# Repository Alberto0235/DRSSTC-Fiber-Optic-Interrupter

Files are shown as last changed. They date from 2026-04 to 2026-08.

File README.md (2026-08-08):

# ⚡ DRSSTC Fiber-Optic Interrupter — V1.2

<p align="left">
  
  
  
  
  
</p>

-----

## 📋 Project Summary

This repository contains the hardware design for a custom interrupter control board built for a Dual Resonant Solid State Tesla Coil (DRSSTC).

While the high-power driver is the "brain" of the system, the interrupter plays a fundamental role: it generates the PWM signal that is sent to the driver, which in turn generates the gate drive pulses to modulate the Tesla Coil's output.

Operating near a resonant RF system means dealing with significant EMI. To address this, the board relies on fiber optic transmitters to electrically isolate the control logic from the high-voltage side, alongside a controlled-impedance layout for high-speed digital interfaces and a hardware-level safety interlocking system.

Key features include:

  * **Total galvanic isolation** of the control outputs via 2 fiber optic channels, featuring a versatile dual-footprint design.
  * **Deterministic hardware safety chain** (E-brake) capable of cutting optical output power and halting MCU timers.
  * **Controlled-impedance routing** on USB, FSMC, and SDIO interfaces.
  * **Flexible power architecture** supporting USB-C bus power or an optional rechargeable battery (e.g., Samsung 30Q 3000mAh) via a dedicated charging IC and a 3.3V buck regulator.

-----

PCB Render

🔗 **Explore the design:** [View the full Schematic (PDF)](Hardware/Exports/Schematic_Interrupter_v1.2.pdf)
> **Status Note:** The hardware design, fabrication, and assembly are complete. The board is currently undergoing bench validation and bring-up, while firmware development (STM32CubeMX HAL + application layer) is in progress.

-----

## 🔧 Key Specifications & Features

| Parameter | Value / Detail |
|---|---|
| **MCU** | STM32F405VGT6 — ARM Cortex-M4 @ 168 MHz, LQFP-100 |
| **PCB Layers** | 4-layer controlled-impedance stackup (JLCPCB JLC04161H-3313) |
| **System Rail** | 3.3 V — generated by a synchronous buck converter |
| **Power Input** | USB-C (bus power) or Li-ion battery — Charger/Power-path: BQ24075RGT · Protection: BQ29700DSERG · Buck: TLV62569DBV |
| **Outputs** | 2x Galvanically isolated fiber optic channels (Dual-footprint: HFBR-1412TZ or IF E97) |
| **Optical Rail** | 3.3 V — Switched by a PMOS tied to the E-brake safety chain |
| **Safety Chain** | Hardware E-brake: cuts PMOS power + triggers interrupts to halt STM32 timers |
| **Display Interface** | FSMC 16-bit 8080 Mode — 50 Ω impedance-controlled. Target display: ER-TFT028A2-4 (IM3=0, IM2=0, IM1=0, IM0=1). |
| **Storage** | SD card via SDIO — 50 Ω impedance-controlled |
| **USB Interface** | Full-speed USB 2.0 — 90 Ω differential impedance |
| **Clock Source** | External 24 MHz crystal oscillator |
| **User Interface** | Rotary encoders + tactile push buttons |
| **External/Debug** | UART header (with 100 Ω series resistors) for debug or additional modules + Tag-Connect SWD |
| **Length Matching** | Applied on USB D+/D−, FSMC data/address bus, and SDIO data lines |
| **Design Tool** | KiCad 9.0 |

-----

## 🏆 Hardware Engineering Highlights

This section details some of the specific design choices made during the layout routing and stackup definition.

### 📡 Signal Integrity

  * **USB 2.0 (Full Speed):** The D+/D− pair is routed as a 90 Ω differential pair, calculated using the Saturn PCB Toolkit. Intra-pair skew is minimized across the routing path.
  * **FSMC & SDIO:** Routed at 50 Ω characteristic single-ended impedance. For the SDIO protocol, 33 Ω series termination resistors were placed as close as possible to the MCU source to suppress reflections.
  * **UART / External Header:** 100 Ω series resistors were added to the TX/RX lines near the connector. Since no TVS diodes were implemented at the silicon level for this header, these resistors provide a basic level of protection against spikes during manual probing or module connection.

| USB 2.0 (90 Ω Differential Target) | FSMC & SDIO (50 Ω Single-Ended Target) |
| :---: | :---: |
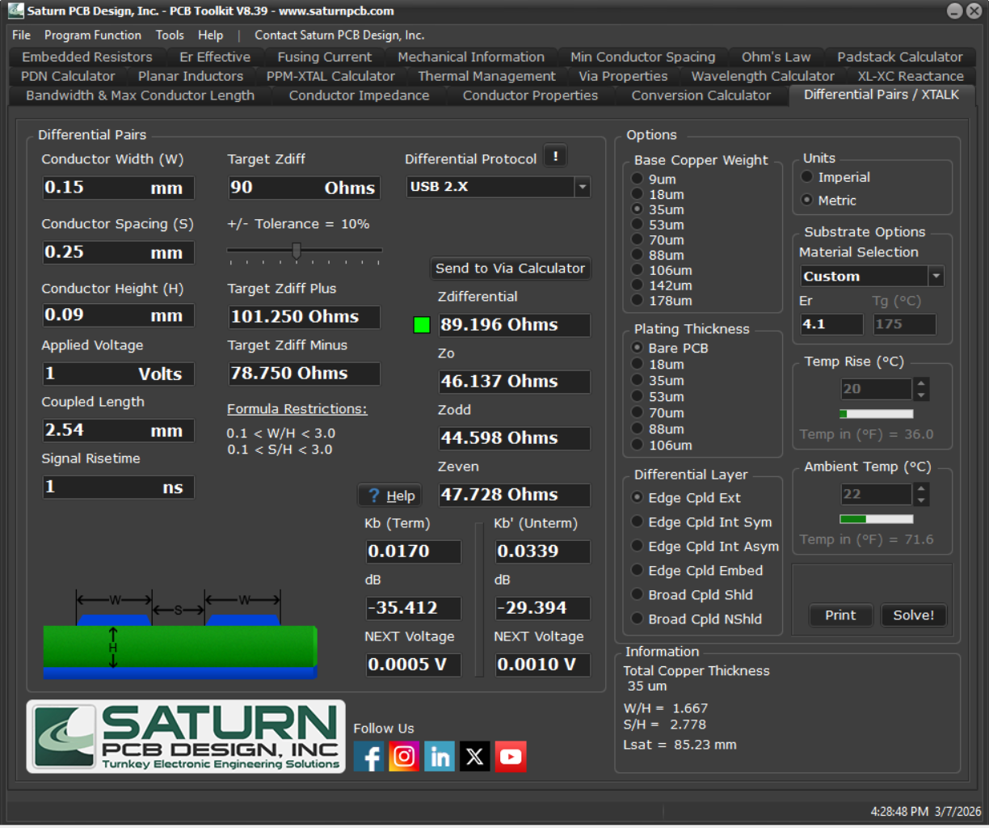
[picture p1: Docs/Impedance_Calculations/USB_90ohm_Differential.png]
Saturn PCB USB
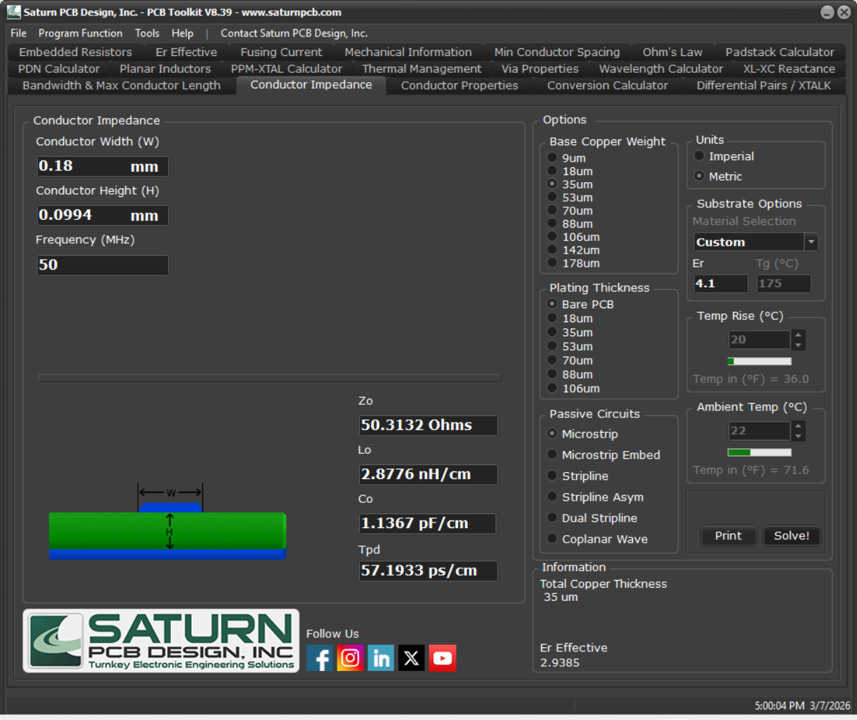
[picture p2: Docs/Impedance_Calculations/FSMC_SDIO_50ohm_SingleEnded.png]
Saturn PCB SDIO
|  |  |

### 🧱 Stackup & Routing Strategy

  * **4-Layer Stackup:** Configured as `Signal+PWR` / `GND` / `GND` / `Signal+PWR`.
  * **Return Paths:** Layers 2 and 3 provide solid, unbroken ground reference planes for the high-speed routing on the top and bottom layers.
  * **Layer Transitions:** Whenever a high-speed signal transitions from Layer 1 to Layer 4, adjacent GND stitching vias were placed next to the signal via to ensure an uninterrupted return current path between the two ground planes.

-----

## 🔒 Safety Architecture

  * **Galvanic Isolation & Transmitter Flexibility:** The commands sent to the driver leave the board exclusively through the fiber optic transmitters. This prevents ground loops and high-voltage transients from traveling back into the control board logic. To maximize flexibility, each of the two optical channels features a dual-footprint design. You can independently populate either an **HFBR-1412TZ** or an **IF E97** transmitter per channel. The onboard current-limiting resistors are specifically calculated and routed for these two standard components.
  * **Hardware E-brake Mechanism:**
      * The E-brake switch is normally closed (NC) to GND. When pressed — or if the cable is accidentally disconnected — a pull-up resistor drives the PMOS gate to 3.3 V, switching it off. This ensures the system fails safe on cable break, not just on deliberate actuation.
      * **Action 1 (Hardware):** Pressing the E-brake disconnects the GND path. This immediately switches off a PMOS on the 3.3V optical rail, physically de-energizing the fiber transmitters and guaranteeing zero output, completely independent of the microcontroller's state.
      * **Action 2 (MCU IRQ):** The same physical event asserts a hardware interrupt on the STM32, halting the PWM timers in the fastest possible IRQ context.
      * **Action 3 (Software IRQ):** A software-level handler serves as a secondary redundant stop mechanism.

-----

## 📁 Repository Structure

```text
DRSSTC-Interrupter/
│
├── Hardware/
│   ├── KiCad/
│   │   ├── Interrupter/              ← KiCad project files
│   │   └── Libraries/                ← Additional libraries
│   └── Exports/
│       ├── Schematic_Interrupter_v1.2.pdf
│       └── PCB_v1.2.png
│
├── Fabrication/
│   ├── Gerbers/
│   ├── BOM_Interrupter_v1.2.csv
│   └── InteractiveBOM.html
│
├── Docs/
│   ├── Impedance_Calculations/
│   │   ├── USB_90ohm_Differential.png
│   │   └── FSMC_SDIO_50ohm_SingleEnded.png
│   └── Stackup/
│       └── JLCPCB_Stackup_Reference.png
│
├── Firmware/
│   └── STM32CubeMX/
│       └── Interrupter.ioc           ← Peripheral configuration (WIP)
│
└── README.md
```

-----

## 🛠️ Tools Used

| Tool | Version | Purpose |
|---|---|---|
| **KiCad EDA** | 9.0 | Full schematic capture and 4-layer PCB layout |
| **STM32CubeMX** | 6.16.0 | MCU peripheral configuration, clock tree, HAL code generation *(WIP)* |
| **Saturn PCB Toolkit** | 8.39 | Controlled impedance calculation (90 Ω differential and 50 Ω single-ended) |

-----

## ⚠️ Disclaimer

This project outlines a control board intended for use with high-voltage equipment capable of generating potentially lethal electrical discharges. All hardware documentation in this repository is provided **for educational and portfolio purposes only**. The author assumes no liability for any damage, injury, or loss resulting from the use or misuse of this material.

-----

## 👤 Author

**Alberto Marrone**
MSc Student in Electronics Engineering — Politecnico di Milano [LinkedIn](https://linkedin.com/in/alberto-marrone-444192274)

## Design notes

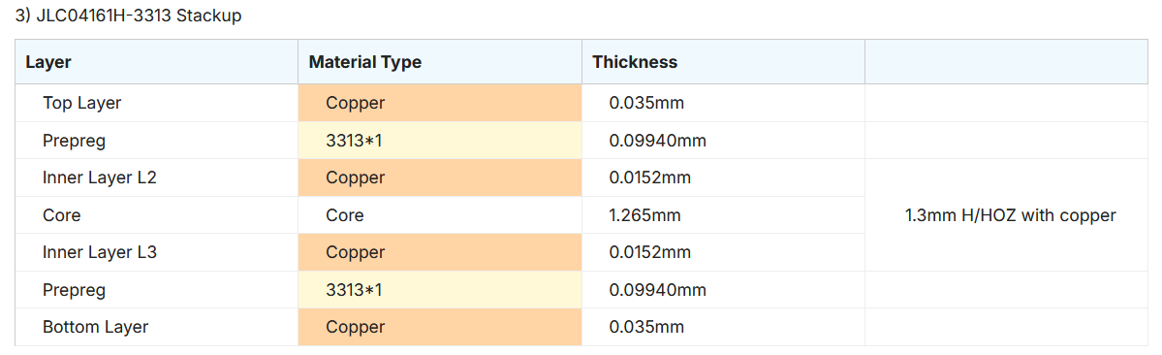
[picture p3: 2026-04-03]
Docs/Stackup/JLCPCB_Stackup_Reference.png

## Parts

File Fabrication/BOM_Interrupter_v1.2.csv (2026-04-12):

Reference | Qty | Value | DNP | Exclude from BOM | Exclude from Board | Footprint | Datasheet | Manufacturer_Part_Number | Vendor | Link
BT1 | 1 | Keystone 1043 |  |  |  | Imported:Keystone 1043 | https://www.mouser.it/datasheet/3/201/1/1043.pdf | 1043 | Mouser | https://www.mouser.it/ProductDetail/Keystone-Electronics/1043?qs=%2F7TOpeL5Mz6j%2FnxeOA1rsg%3D%3D
C1,C6,C7,C9,C11,C12,C13,C14,C15,C16,C17,C19,C22,C23,C25,C26,C30,C32,C37,C38,C39,C40,C41,C42,C47,C49,C50,C52,C53,C55,C56,C57,C58 | 33 | 100n |  |  |  | Capacitor_SMD:C_0402_1005Metric | https://pim.murata.com/asset/pim4/ceramicCapacitorSMD/GRT155R71H104KE01-01A-EN_PDF_CERAMICCAPACITORSMD | GRT155R71H104KE01J | Mouser | https://www.mouser.it/ProductDetail/Murata-Electronics/GRT155R71H104KE01J?qs=d0WKAl%252BL4Kar2U0zDlkjeg%3D%3D
C2,C8,C20,C21 | 4 | 2.2u |  |  |  | Capacitor_SMD:C_0805_2012Metric | https://datasheets.kyocera-avx.com/KGM_X7R.pdf | KGM21AR71E225KU | Mouser | https://www.mouser.it/ProductDetail/KYOCERA-AVX/KGM21AR71E225KU?qs=Jm2GQyTW%2FbhCn4KuUMBp1Q%3D%3D
C3,C4,C31 | 3 | 10p |  |  |  | Capacitor_SMD:C_0402_1005Metric | https://pim.murata.com/asset/pim4/ceramicCapacitorSMD/GRM1555C1H100FA01-01A-EN_PDF_CERAMICCAPACITORSMD | GRM1555C1H100FA01D | Mouser | https://www.mouser.it/ProductDetail/Murata-Electronics/GRM1555C1H100FA01D?qs=ouTquLLW2S6Ql85QMjDTPQ%3D%3D
C5,C18,C36,C48 | 4 | 1u |  |  |  | Capacitor_SMD:C_0603_1608Metric | https://product.tdk.com/system/files/dam/doc/product/capacitor/ceramic/mlcc/catalog/mlcc_commercial_general_en.pdf | C1608X7R1H105K080AB | Mouser | https://www.mouser.it/ProductDetail/TDK/C1608X7R1H105K080AB?qs=efUn273yAhdzCWVW9RXgig%3D%3D
C10,C24,C29,C35,C51,C54 | 6 | 4.7u |  |  |  | Capacitor_SMD:C_0805_2012Metric | https://www.mouser.it/datasheet/3/76/3/GRM21BZ7YA475KE15_01A.pdf | GRM21BZ7YA475KE15K | Mouser | https://www.mouser.it/ProductDetail/Murata-Electronics/GRM21BZ7YA475KE15K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
C27,C28,C33,C34 | 4 | 10u |  |  |  | Capacitor_SMD:C_0805_2012Metric | https://www.mouser.it/datasheet/3/76/2/GRM21BZ71E106KE15_01A.pdf | GRM21BZ71E106KE15L | Mouser | https://www.mouser.it/ProductDetail/Murata-Electronics/GRM21BZ71E106KE15L?qs=Ey7%2FXF42M3fdXe9bIpCO9w%3D%3D
C43,C44,C45,C46 | 4 | 10n |  |  |  | Capacitor_SMD:C_0603_1608Metric | https://datasheets.kyocera-avx.com/AutoMLCCKAF.pdf | KAF15AR71H103JM | Mouser | https://www.mouser.it/ProductDetail/KYOCERA-AVX/KAF15AR71H103JM?qs=OcgtsXO%252B3gvrQfm2NimJjQ%3D%3D
D1,D2,D3,D4,D5,D7,D9 | 7 | LED |  |  |  | Imported:TOPLED E1608 | https://eu.mouser.com/datasheet/3/5912/1/KB_DELSS2.12_EN.pdf,https://eu.mouser.com/datasheet/3/5912/1/KO_DELPS1.22_EN.pdf,https://eu.mouser.com/datasheet/3/59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 | KB DELSS2.12-THUH-34-2686,KO DELPS1.22-UGVI-24-H3Q4-20-S,KS DELPS1.22-TIVH-68-H3Q4-20-S,KT DELSS1.12-AYBZ-36-N626 | Mouser | https://eu.mouser.com/ProductDetail/ams-OSRAM/KB-DELSS2.12-THUH-34-2686
D6,D8 | 2 | IF-E97 |  |  |  | Imported:IF-E97 | https://i-fiberoptics.com/pdf/ife97-2-20.pdf | IF-E97 | DigiKey | https://www.digikey.es/es/products/detail/industrial-fiber-optics/IF-E97/272338
ENC1,ENC2 | 2 | PEC11R-4220F-S0024 |  |  |  | Imported:PEC11R4220FS0024 | https://www.bourns.com/docs/Product-Datasheets/PEC11R.pdf | PEC11R-4220F-S0024 | Mouser | https://www.mouser.it/ProductDetail/Bourns/PEC11R-4015F-S0024?qs=Zq5ylnUbLm4l0nvCUCX4Xw%3D%3D
FB1,FB2,FB3 | 3 | 120Ω @ 100MHz |  |  |  | Inductor_SMD:L_0603_1608Metric | https://eu.mouser.com/datasheet/3/76/2/QNFA9122.pdf | BLM18SG121TZ1D | Mouser | https://eu.mouser.com/ProductDetail/Murata-Electronics/BLM18SG121TZ1D?qs=lEfY3O89AqkcqxjERGLMfg%3D%3D
FID1,FID2,FID3,FID4,FID5,FID6 | 6 | Fiducial |  | Excluded from BOM |  | Fiducial:Fiducial_1mm_Mask2mm | ~ | Fiducial | ~ | ~
H1,H2,H3,H4 | 4 | M3 |  | Excluded from BOM |  | MountingHole:MountingHole_3.2mm_M3_Pad_Via | ~ | MountingHole-M3 | ~ | ~
IC1 | 1 | STM32F405VGT6 |  |  |  | Imported:STM32F405VGT6 | https://www.st.com/resource/en/datasheet/stm32f405zg.pdf | STM32F405VGT6 | Mouser | https://www.mouser.it/ProductDetail/STMicroelectronics/STM32F405VGT6?qs=Z8%252BeY1k3TIJiWie7HpfDCQ%3D%3D
IC2 | 1 | BQ29700DSER |  |  |  | Imported:BQ29700 | http://www.ti.com/lit/ds/symlink/bq2971.pdf | BQ29700DSER | Mouser | https://eu.mouser.com/ProductDetail/Texas-Instruments/BQ29700DSER?qs=%2Fd%252BFzHvH4c3zNh7Hkm%2Fvbw%3D%3D
J1 | 1 | Conn_01x04 |  |  |  | Connector_PinSocket_2.00mm:PinSocket_1x04_P2.00mm_Vertical | ~ | ~ | ~ | ~
J2 | 1 | USB_C_Receptacle_USB2.0_16P |  |  |  | Connector_USB:USB_C_Receptacle_GCT_USB4105-xx-A_16P_TopMnt_Horizontal | https://www.mouser.com/catalog/specsheets/Global_Connector_Technology_usb4105.pdf | USB4105-GF-A-120 | Mouser | https://eu.mouser.com/ProductDetail/GCT/USB4105-GF-A-120?qs=QNEnbhJQKva%252Bjxw%2FpEjDhQ%3D%3D
J3 | 1 | TagConnect |  | Excluded from BOM |  | Connector:Tag-Connect_TC2030-IDC-NL_2x03_P1.27mm_Vertical | https://www.tag-connect.com/wp-content/uploads/bsk-pdf-manager/TC2030-CTX_1.pdf | ~ | ~ | ~
J4 | 1 | ER-CON50HT-1 |  |  |  | Imported:ER-CON50HT-1 | https://www.buydisplay.com/download/connector/ER-CON50HT-1.pdf | ER-CON50HT-1 | BuyDispaly | https://www.buydisplay.com/50-pin-0-5mm-pitch-top-contact-zif-connector-fpc-connector
J5 | 1 | DM3AT-SF-PEJM5 |  |  |  | Imported:DM3AT-SF-PEJM5 | https://www.mouser.it/datasheet/3/731/1/DM3AT_SF_PEJM5_CL0609_0031_0_00_2DDrawing_0000947170.pdf | DM3AT-SF-PEJM5 | Mouser | https://www.mouser.it/ProductDetail/Hirose-Connector/DM3AT-SF-PEJM5?qs=LZSZKJVF%252B2WTDKp%252BR7IYAQ%3D%3D
JP1,JP2,JP3,JP4 | 4 | SolderJumper |  | Excluded from BOM |  | Jumper:SolderJumper-3_P1.3mm_Bridged2Bar12_RoundedPad1.0x1.5mm_NumberLabels | ~ | SolderJumper | ~ | ~
L1 | 1 | 2.2u |  |  |  | Imported:ETQ-P3M2R2HFP | https://industrial.panasonic.com/cdbs/www-data/pdf/AGL0000/AGL0000C67.pdf | ETQ-P3M2R2HFP | Mouser | https://www.mouser.it/ProductDetail/Panasonic/ETQ-P3M2R2HFP?qs=f9yNj16SXrJQaaX5knv6PA%3D%3D
Q1,Q2,Q4,Q5,Q6 | 5 | PMV240ENEAR |  |  |  | Package_TO_SOT_SMD:SOT-23 | https://assets.nexperia.com/documents/data-sheet/PMV240ENEA.pdf | PMV240ENEAR | Mouser | https://www.mouser.it/ProductDetail/Nexperia/PMV240ENEAR?qs=olJun0bQHM8vrl7UqGNaQw%3D%3D
Q3 | 1 | PMV250EPEAR |  |  |  | Package_TO_SOT_SMD:SOT-23 | https://assets.nexperia.com/documents/data-sheet/PMV250EPEA.pdf | PMV250EPEA | Mouser | https://www.mouser.it/ProductDetail/Nexperia/PMV250EPEAR?qs=Yna0arPQ0CTtAa8k6X9CyQ%3D%3D
R1,R2,R3,R5,R8,R9 | 6 | 33 |  |  |  | Resistor_SMD:R_0402_1005Metric | https://www.vishay.com/docs/20132/rca-sre3.pdf | RCA040233R0FKEDSR | Mouser | https://eu.mouser.com/ProductDetail/Vishay/RCA040233R0FKEDSR?qs=4dK74SdgGtwI6tlGJ%2FGTmQ%3D%3D
R4,R12,R16,R25,R26,R34,R42,R43,R44,R45,R46,R47,R48,R49,R50,R51,R52,R53,R54,R55,R56,R57,R58,R59,R60,R61,R67,R76 | 28 | 10k |  |  |  | Resistor_SMD:R_0402_1005Metric | https://eu.mouser.com/datasheet/3/508/1/PYU_AC_51_ROHS_L.pdf | AC0402FR-0710KL | Mouser | https://eu.mouser.com/ProductDetail/YAGEO/AC0402FR-0710KL?qs=yhV1fb9g%2FKYkR5U3B7upEQ%3D%3D
R6,R7,R11,R15,R79 | 5 | 100 |  |  |  | Resistor_SMD:R_0402_1005Metric | https://eu.mouser.com/datasheet/3/508/1/PYU_AC_51_ROHS_L.pdf | AC0402FR-13100RL | Mouser | https://eu.mouser.com/ProductDetail/YAGEO/AC0402FR-13100RL?qs=AQlKX63v8RslM5cufGduxw%3D%3D
R10 | 1 | 0 |  |  |  | Resistor_SMD:R_0402_1005Metric | https://www.vishay.com/docs/20035/dcrcwe3.pdf | CRCW04020000Z0ED | Mouser | https://eu.mouser.com/ProductDetail/Vishay/CRCW04020000Z0ED?qs=OlqPY1Ciranv3qgeAHCodg%3D%3D
R13,R40,R71,R77 | 4 | 220 |  |  |  | Resistor_SMD:R_0402_1005Metric | https://eu.mouser.com/datasheet/3/508/1/PYU_AC_51_ROHS_L.pdf | AC0402FR-7W220RL | Mouser | https://eu.mouser.com/ProductDetail/YAGEO/AC0402FR-7W220RL?qs=mQk0km4IMDd0ZPGIeAEF8Q%3D%3D
R14,R35,R41,R72,R78 | 5 | 100k |  |  |  | Resistor_SMD:R_0402_1005Metric | https://eu.mouser.com/datasheet/3/508/1/PYU_AC_51_ROHS_L.pdf | AC0402FR-7W100KL | Mouser | https://eu.mouser.com/ProductDetail/YAGEO/AC0402FR-7W100KL?qs=mQk0km4IMDfW7chanOKcig%3D%3D
R17,R18 | 2 | 5.1k |  |  |  | Resistor_SMD:R_0402_1005Metric | https://eu.mouser.com/datasheet/3/508/1/PYu-AF_51_RoHS_L_9.pdf | AF0402FR-075K1L | Mouser | https://eu.mouser.com/ProductDetail/YAGEO/AF0402FR-075K1L?qs=HEu%2FF%2FCqxzKC2GH3mOffUw%3D%3D
R19,R20,R29 | 3 | 1.5k |  |  |  | Resistor_SMD:R_0402_1005Metric | https://eu.mouser.com/datasheet/3/508/1/PYU_AC_51_ROHS_L.pdf | AC0402FR-7W1K5L | Mouser | https://eu.mouser.com/ProductDetail/YAGEO/AC0402FR-7W1K5L?qs=mQk0km4IMDcl1A2lKmX%2F2w%3D%3D
R21 | 1 | 330 |  |  |  | Resistor_SMD:R_0402_1005Metric | https://eu.mouser.com/datasheet/3/508/1/PYU_AC_51_ROHS_L.pdf | AC0402FR-7W330RL | Mouser | https://eu.mouser.com/ProductDetail/YAGEO/AC0402FR-7W330RL?qs=mQk0km4IMDczemHdChyFNA%3D%3D
R22 | 1 | 2.2k |  |  |  | Resistor_SMD:R_0402_1005Metric | https://eu.mouser.com/datasheet/3/508/1/PYu-AF_51_RoHS_L_9.pdf | AF0402FR-072K2L | Mouser | https://eu.mouser.com/ProductDetail/YAGEO/AF0402FR-072K2L?qs=HEu%2FF%2FCqxzLbE%252B9PoedSew%3D%3D
R23,R24 | 2 | 5.1M |  |  |  | Resistor_SMD:R_0402_1005Metric | https://eu.mouser.com/datasheet/3/508/1/PYu-AF_51_RoHS_L_9.pdf | AF0402FR-075M1L | Mouser | https://eu.mouser.com/ProductDetail/YAGEO/AF0402FR-075M1L?qs=tggtontpCXODq21yFdoYyQ%3D%3D
R27 | 1 | 68k |  |  |  | Resistor_SMD:R_0402_1005Metric | https://eu.mouser.com/datasheet/3/508/1/PYU_AC_51_ROHS_L.pdf | AC0402FR-7W68KL | Mouser | https://eu.mouser.com/ProductDetail/YAGEO/AC0402FR-7W68KL?qs=mQk0km4IMDe05rLmfXlp6Q%3D%3D
R28 | 1 | 1.8k |  |  |  | Resistor_SMD:R_0402_1005Metric | https://eu.mouser.com/datasheet/3/508/1/PYU_AC_51_ROHS_L.pdf | AC0402FR-071K8L | Mouser | https://eu.mouser.com/ProductDetail/YAGEO/AC0402FR-071K8L?qs=yhV1fb9g%2FKZuYNO5wsV9Pw%3D%3D
R30 | 1 | 470 |  |  |  | Resistor_SMD:R_0402_1005Metric | https://eu.mouser.com/datasheet/3/508/1/PYU_AC_51_ROHS_L.pdf | AC0402FR-7W470RL | Mouser | https://eu.mouser.com/ProductDetail/YAGEO/AC0402FR-7W470RL?qs=mQk0km4IMDfWG48tCLZa0w%3D%3D
R31,R32,R62,R63,R64,R65,R66 | 7 | 47k |  |  |  | Resistor_SMD:R_0402_1005Metric | https://www.vishay.com/docs/20035/dcrcwe3.pdf | CRCW040247K0FKED | Mouser | https://eu.mouser.com/ProductDetail/Vishay/CRCW040247K0FKED?qs=rzhQWu8UUS0SPbmGf0DOIg%3D%3D
R33 | 1 | 453k |  |  |  | Resistor_SMD:R_0402_1005Metric | https://industrial.panasonic.com/cdbs/www-data/pdf/RDA0000/AOA0000C304.pdf | ERJ-2RKF4533X | Mouser | https://eu.mouser.com/ProductDetail/Panasonic/ERJ-2RKF4533X?qs=YMBIwoNQYdVZQ316LHSXpQ%3D%3D
R36,R37,R38,R39 | 4 | 4.7 |  |  |  | Resistor_SMD:R_0402_1005Metric | https://eu.mouser.com/datasheet/3/508/1/PYu-SR_20105_RoHS_L_12.pdf | SR0402FR-7T4R7L | Mouser | https://eu.mouser.com/ProductDetail/YAGEO/SR0402FR-7T4R7L?qs=qpJ%252B%252B%252Bdg6p1e9tckOyHPxA%3D%3D
R68,R73 | 2 | 27 |  |  |  | Resistor_SMD:R_0805_2012Metric | https://industrial.panasonic.com/cdbs/www-data/pdf/RDO0000/AOA0000C331.pdf | ERJ-P06F27R0V | Mouser | https://eu.mouser.com/ProductDetail/Panasonic/ERJ-P06F27R0V?qs=iIVTEDlrHA3pDyX1uO2THw%3D%3D
R69,R70,R74,R75 | 4 | 47 |  |  |  | Resistor_SMD:R_0805_2012Metric | https://industrial.panasonic.com/cdbs/www-data/pdf/RDO0000/AOA0000C331.pdf | ERJ-P06F47R0V | Mouser | https://eu.mouser.com/ProductDetail/Panasonic/ERJ-P06F47R0V?qs=iIVTEDlrHA3jXurJ8%2Fb0wQ%3D%3D
SW1,SW2 | 2 | Push |  |  |  | Imported:PTS636SM43JSMTRLFS | https://www.ckswitches.com/media/2779/pts636.pdf | PTS636SM43JSMTR LFS | Mouser | https://eu.mouser.com/ProductDetail/CK/PTS636SM43JSMTR-LFS?qs=%252BXxaIXUDbq0c6yfQESkQsA%3D%3D
SW3 | 1 | SW_DIP_x02 |  |  |  | Imported:A6S-2104-H | https://eu.mouser.com/datasheet/3/39/1/en_a6s.pdf | A6S-2104-H | Mouser | https://eu.mouser.com/ProductDetail/Omron-Electronics/A6S-2104-H?qs=ZP3UR5XsUocCV6WIDeBAHA%3D%3D
SW4 | 1 | SW_SPDT |  |  |  | Imported:EG1206 | https://eu.mouser.com/datasheet/3/315/1/EG1206.pdf | EG1206 | Mouser | https://eu.mouser.com/ProductDetail/E-Switch/EG1206?qs=HKd%2Fp3M7KlUkIGmXpAWCMA%3D%3D
SW5,SW6 | 2 | Push |  |  |  | Imported:B3F_4050 | https://www.mouser.it/datasheet/3/39/1/en_b3f.pdf | B3F-4050 | Mouser | https://www.mouser.it/ProductDetail/Omron-Electronics/B3F-4050?qs=B3tblJ0Nlt9ObBVoLmesBQ%3D%3D
SW7,SW8 | 2 | SW_SPDT | DNP |  |  | Imported:100SP1T1B1M2REH | https://eu.mouser.com/datasheet/3/315/1/100SP1T1B1M2REH.pdf | 100SP1T1B1M2REH | Mouser | https://eu.mouser.com/ProductDetail/E-Switch/100SP1T1B1M2REH?qs=01kh3H%252BlXihCX4kaIcYj8A%3D%3D
SW9 | 1 | Push SPDT |  |  |  | Imported:8161SHCQE2 | https://www.ckswitches.com/media/1395/8060.pdf | 8161SHCQE2 | Mouser | https://eu.mouser.com/ProductDetail/CK/8161SHCQE2?qs=%252BxTWGDfWz02yP7w3eFs9fQ%3D%3D
TH1 | 1 | 10k NTC |  |  |  | Resistor_SMD:R_0603_1608Metric | https://product.tdk.com/system/files/dam/doc/product/sensor/ntc/chip-ntc-thermistor/catalog/tpd_commercial_ntc-thermistor_ntcg_en.pdf | NTCG163JF103FT1A | Mouser | https://www.mouser.it/ProductDetail/TDK/NTCG163JF103FT1A?qs=ZcfC38r4PotFYH9eb1GkAw%3D%3D
TP1,TP2,TP3,TP4,TP5,TP6,TP9 | 7 | TestPoint | DNP |  |  | Imported:S275146R | https://eu.mouser.com/datasheet/3/71/1/S2751R.pdf | S2751-46R | Mouser | https://eu.mouser.com/ProductDetail/Harwin/S2751-46R?qs=DaxoyN%2FvrebM3VuuS3MPNA%3D%3D
TP7,TP8,TP10,TP11,TP12,TP13,TP14 | 7 | TestPoint |  |  |  | Imported:S275146R | https://eu.mouser.com/datasheet/3/71/1/S2751R.pdf | S2751-46R | Mouser | https://eu.mouser.com/ProductDetail/Harwin/S2751-46R?qs=DaxoyN%2FvrebM3VuuS3MPNA%3D%3D
U1 | 1 | USBLC6-2SC6 |  |  |  | Package_TO_SOT_SMD:SOT-23-6 | https://www.st.com/resource/en/datasheet/usblc6-2.pdf | USBLC6-2SC6 | Mouser | https://eu.mouser.com/ProductDetail/STMicroelectronics/USBLC6-2SC6?qs=po45yt2pPpu%2FhNIlwQdTlg%3D%3D
U2 | 1 | BQ24075RGT |  |  |  | Package_DFN_QFN:VQFN-16-1EP_3x3mm_P0.5mm_EP1.6x1.6mm | http://www.ti.com/lit/ds/symlink/bq24075.pdf | BQ24075RGTR | Mouser | https://eu.mouser.com/ProductDetail/Texas-Instruments/BQ24075RGTR?qs=XGzIaZb%2FFYKTADIJv746hA%3D%3D
U3,U4 | 2 | CSD16406Q3 |  |  |  | Imported:CSD16406Q3 | https://www.ti.com/lit/ds/symlink/csd16406q3.pdf?ts=1772560257556 | CSD16406Q3 | Mouser | https://eu.mouser.com/ProductDetail/Texas-Instruments/CSD16406Q3?qs=SuDOdTVxq4Wogv4PDdDFZA%3D%3D
U5 | 1 | TLV62569DBV |  |  |  | Package_TO_SOT_SMD:SOT-23-5 | http://www.ti.com/lit/ds/symlink/tlv62569.pdf | TLV62569DBVR | Mouser | https://eu.mouser.com/ProductDetail/Texas-Instruments/TLV62569DBVR?qs=0C8XhJW8e4oaylc%252BzBrCmA%3D%3D
U6,U7 | 2 | HFBR-1412TZ |  |  |  | Imported:HFBR1412TMZ | https://docs.broadcom.com/docs/AV02-0176EN | HFBR-1412TZ | Mouser | https://eu.mouser.com/ProductDetail/Broadcom-Avago/HFBR-1412TZ?qs=jT9z6tsiFNmBqJ6B3P4Suw%3D%3D
Y1 | 1 | 24MHz |  |  |  | Crystal:Crystal_SMD_Abracon_ABM10-4Pin_2.5x2.0mm | https://eu.mouser.com/datasheet/3/184/1/ABM10N.pdf | ABM10N-24.0000MHZ-10-B1U-T3 | Mouser | https://eu.mouser.com/ProductDetail/ABRACON/ABM10N-24.0000MHZ-10-B1U-T3?qs=bN4HulGPsrF3QJP5K3E1pw%3D%3D

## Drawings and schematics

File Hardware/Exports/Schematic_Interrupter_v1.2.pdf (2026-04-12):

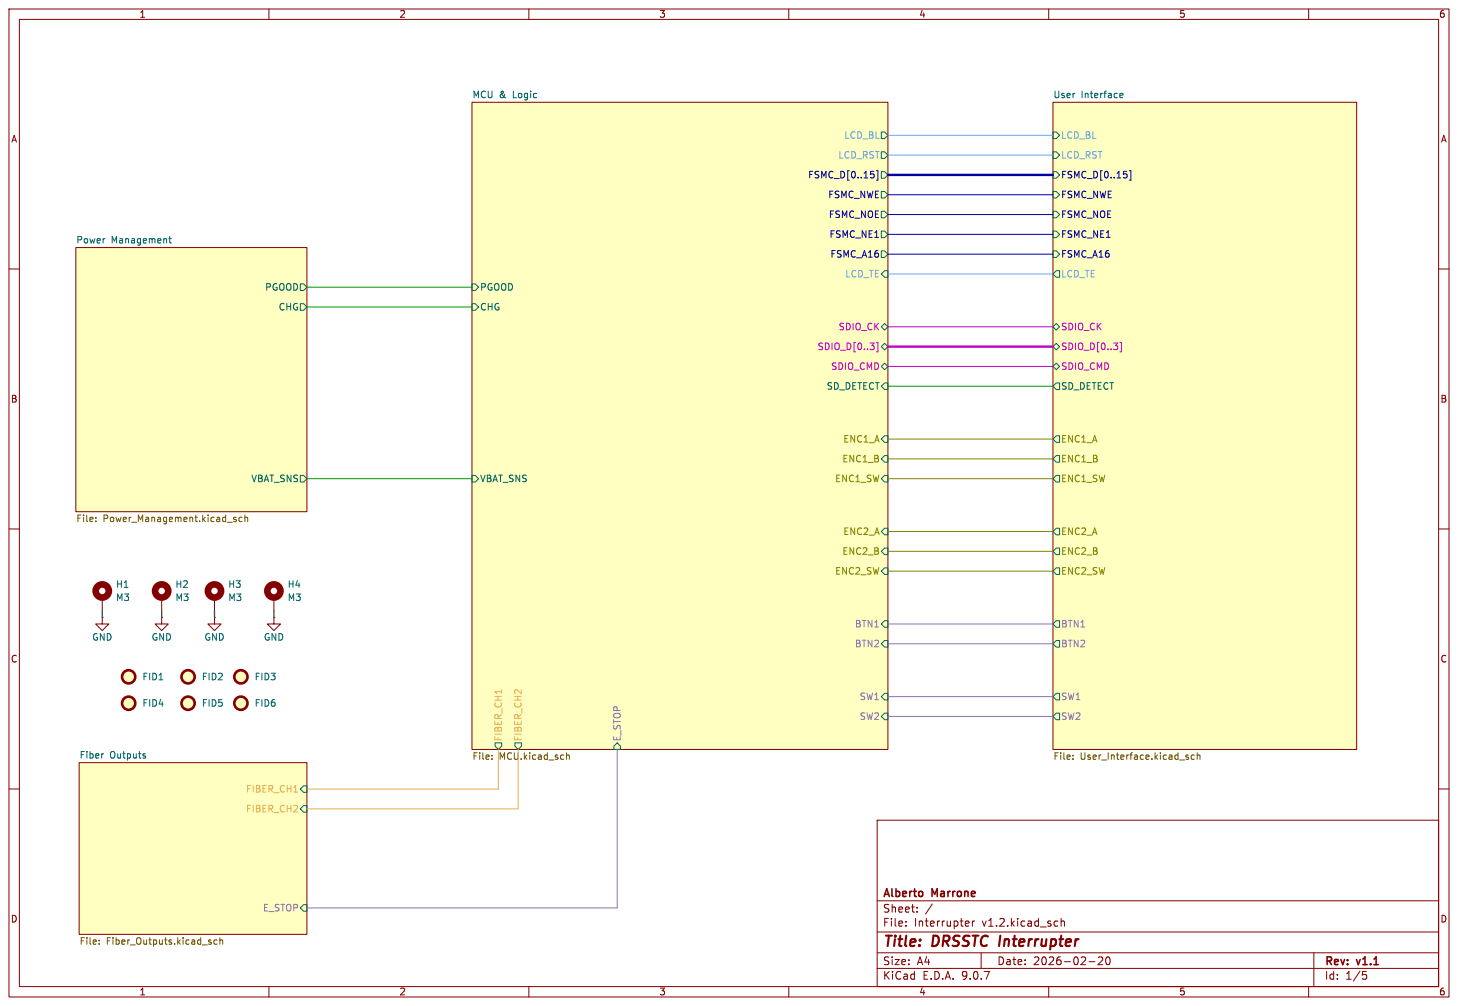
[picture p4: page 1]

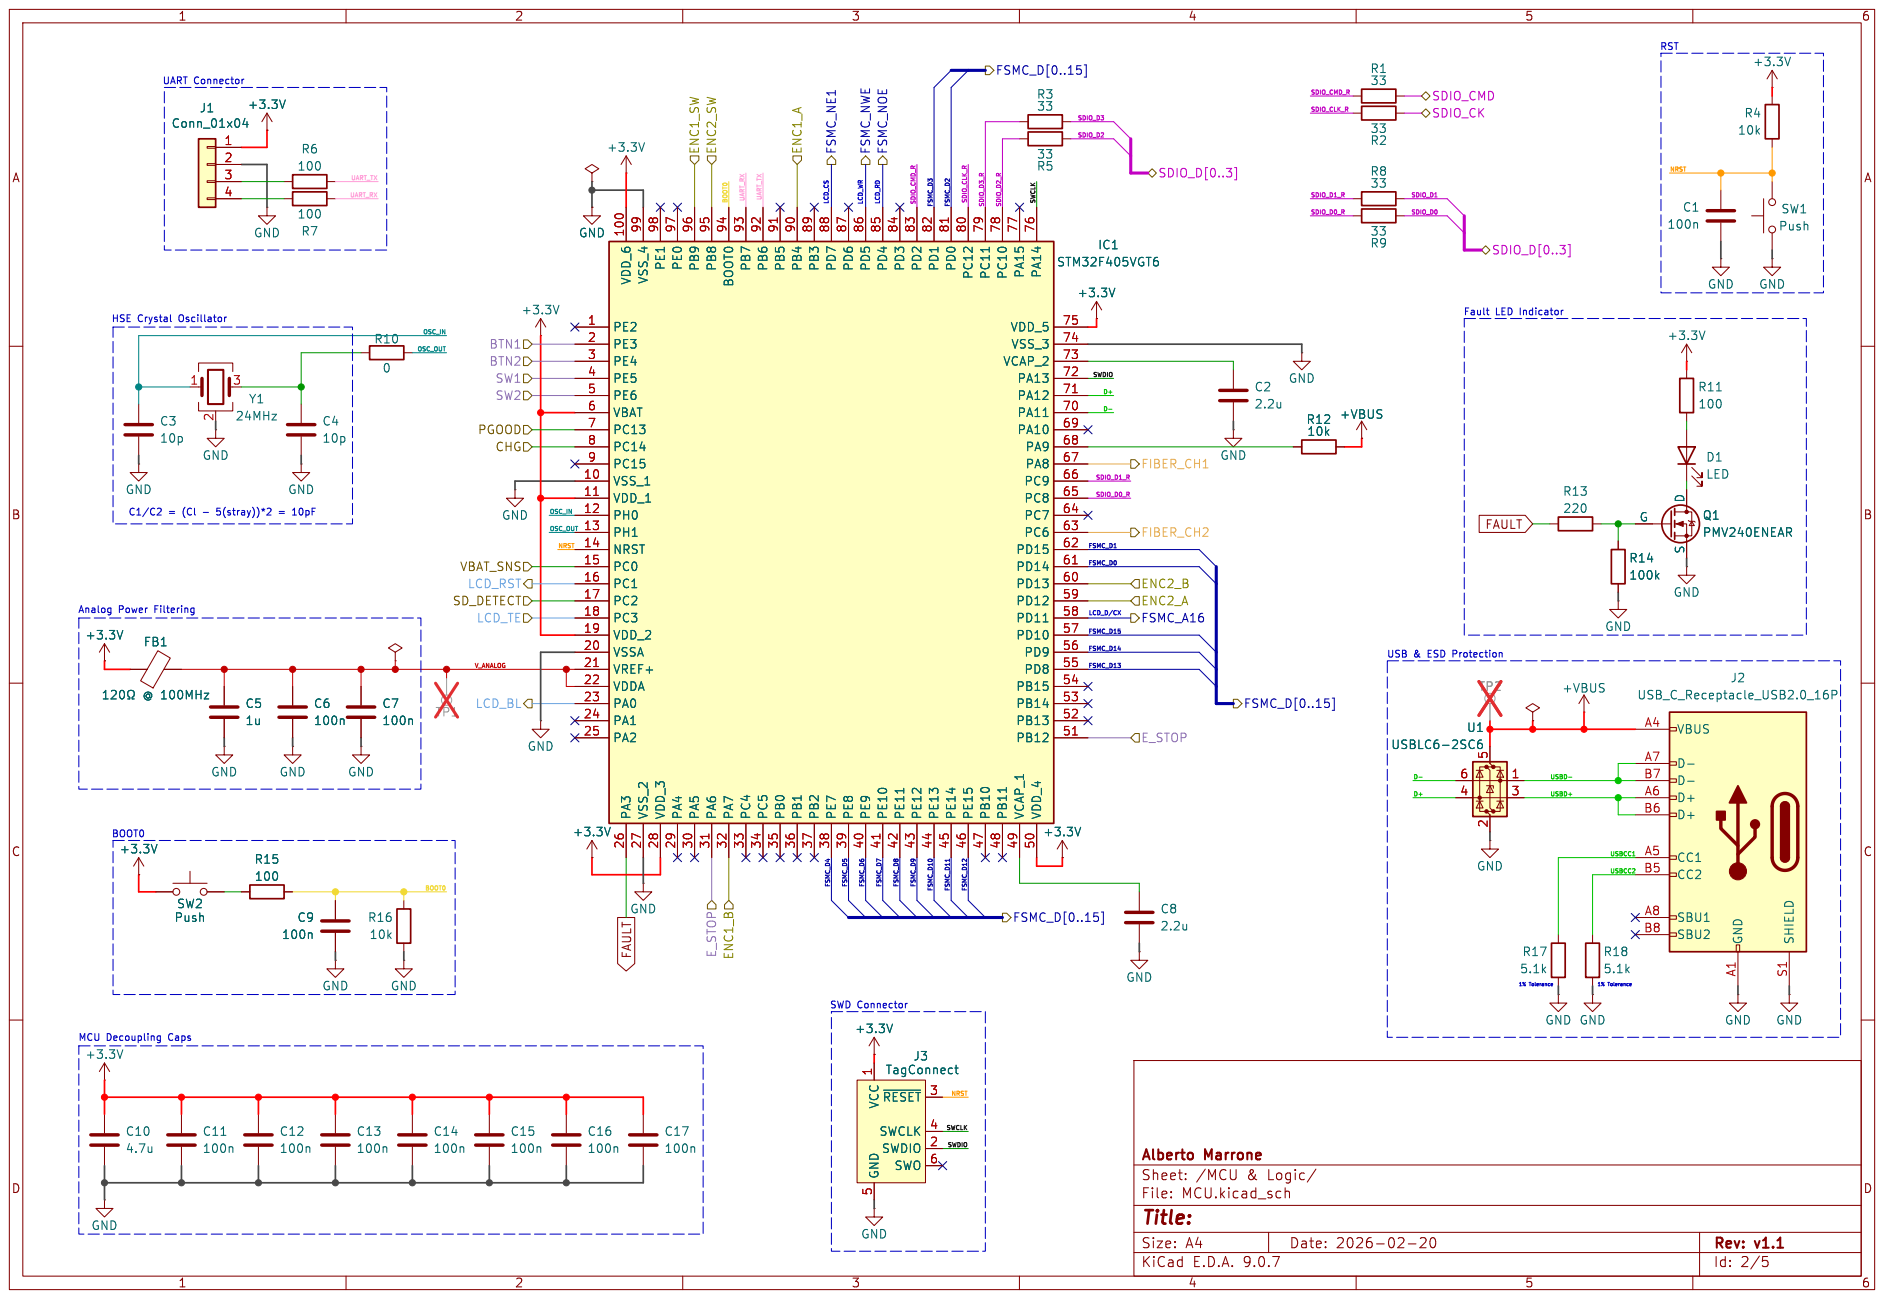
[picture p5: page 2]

5 ~{RESET}3 SWCLK 4 SWDIO 2 SWO 6 C6

5 ~{RESET}3 SWCLK 4 SWDIO 2 SWO 6

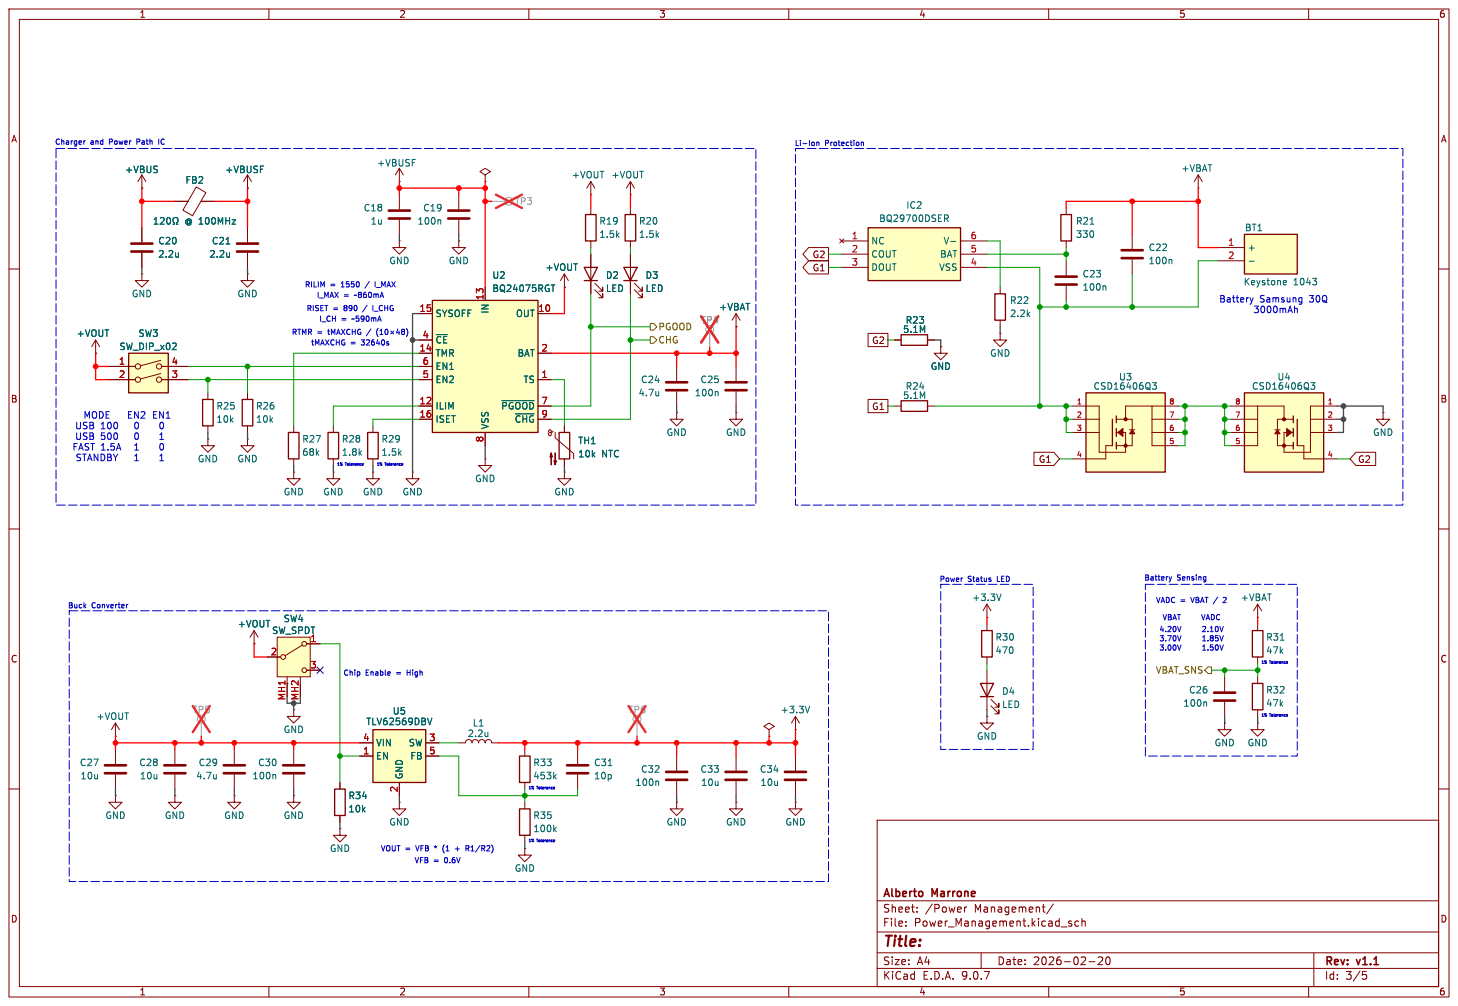
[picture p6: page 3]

Charger and Power Path IC

Chip Enable = High RISET = 890 / I_CHG

8 OUT 10 BAT 2 TS 1 ~{PGOOD}7 ~{CHG}9 U2BQ24075RGT VIN 4 EN 1 GND

8 OUT 10 BAT 2 TS 1 ~{PGOOD}7 ~{CHG}9 +VBAT SW4 SW_SPDT

þÿRTMR  = þÿtMAXCHG  / þÿ(10×48) MODE USB 100 USB 500 FAST 1.5A

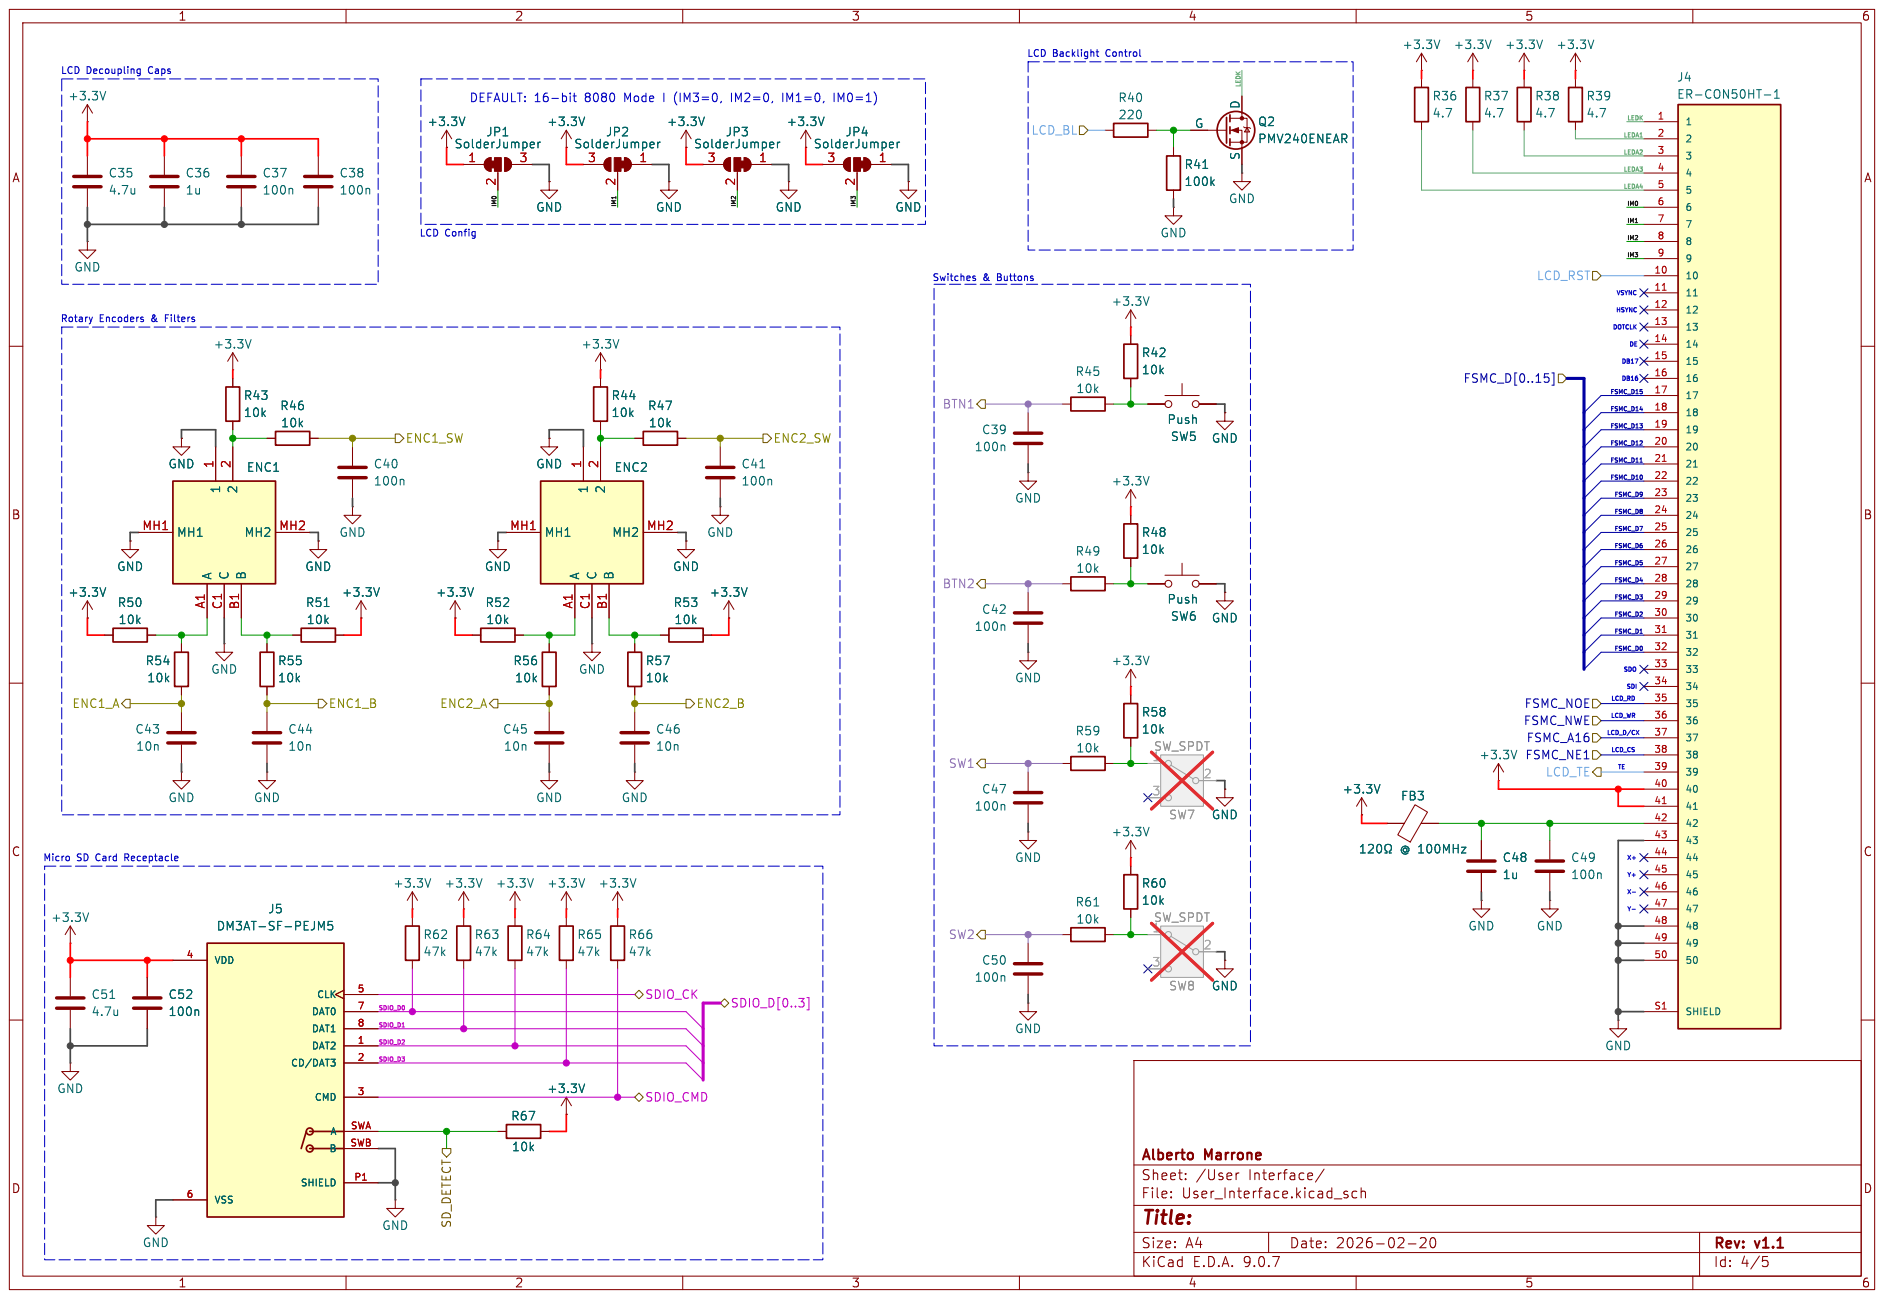
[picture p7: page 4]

SDI Rotary Encoders & Filters

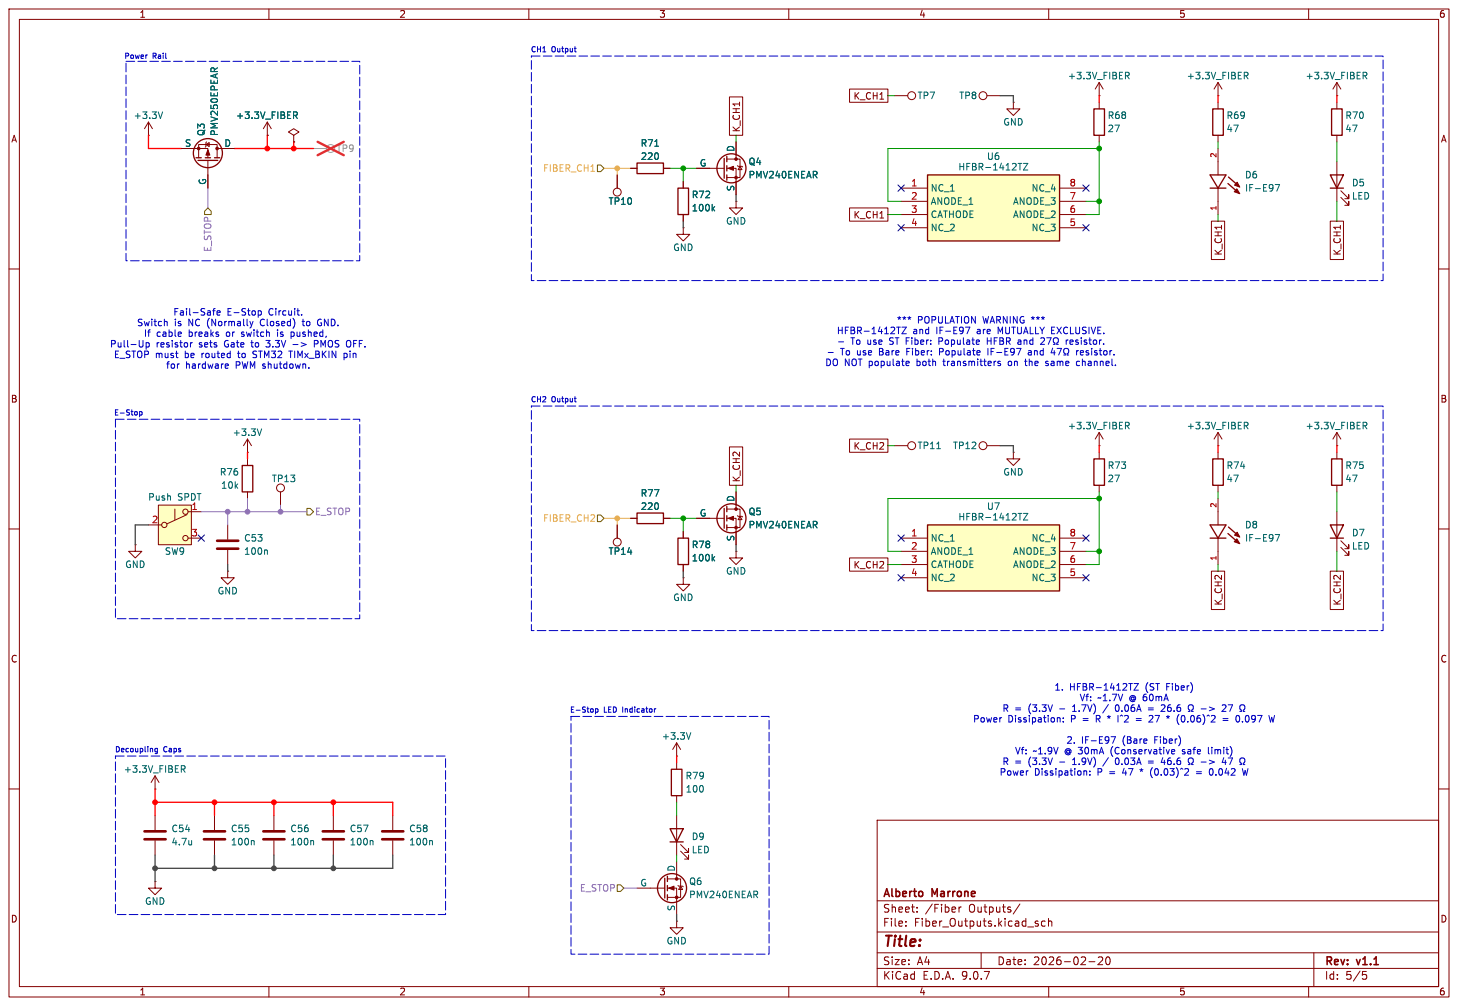
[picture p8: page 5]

If cable breaks or switch is pushed,

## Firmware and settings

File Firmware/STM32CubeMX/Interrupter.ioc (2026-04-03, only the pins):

Mcu.UserName=STM32F405VGTx
PA0-WKUP.GPIO_Label=TIM2_CH1_LCD_BL
PA0-WKUP.Signal=S_TIM2_CH1_ETR
PA11.Signal=USB_OTG_FS_DM
PA12.Signal=USB_OTG_FS_DP
PA13.Signal=SYS_JTMS-SWDIO
PA14.Signal=SYS_JTCK-SWCLK
PA3.GPIO_Label=FAULT_LED_TM5
PA3.Signal=S_TIM5_CH4
PA6.GPIO_Label=TIM8_BKIN_E-STOP
PA6.Signal=TIM8_BKIN
PA7.GPIO_Label=TIM3_CH2_ENC1
PA7.Signal=S_TIM3_CH2
PA8.Signal=S_TIM1_CH1
PA9.Signal=USB_OTG_FS_VBUS
PB12.GPIO_Label=TIM1_BKIN_E-STOP
PB12.Signal=TIM1_BKIN
PB4.GPIO_Label=TIM3_CH1_ENC1
PB4.Signal=S_TIM3_CH1
PB6.GPIO_Label=UART1_TX
PB6.Signal=USART1_TX
PB7.GPIO_Label=UART1_RX
PB7.Signal=USART1_RX
PB8.GPIO_Label=BTN_ENC2
PB8.Signal=GPIO_Input
PB9.GPIO_Label=BTN_ENC1
PB9.Signal=GPIO_Input
PC0.Signal=ADCx_IN10
PC1.GPIO_Label=LCD_RST
PC1.Signal=GPIO_Output
PC10.Signal=SDIO_D2
PC11.Signal=SDIO_D3
PC12.Signal=SDIO_CK
PC13-ANTI_TAMP.GPIO_Label=PGOOD
PC13-ANTI_TAMP.Signal=GPIO_Input
PC14-OSC32_IN.GPIO_Label=CHG
PC14-OSC32_IN.Signal=GPIO_Input
PC2.GPIO_Label=SD_DETECT
PC2.Signal=GPIO_Input
PC3.GPIO_Label=LCD_TE
PC3.Signal=GPIO_Input
PC6.Signal=S_TIM8_CH1
PC8.Signal=SDIO_D0
PC9.Signal=SDIO_D1
PD0.Signal=FSMC_D2
PD1.Signal=FSMC_D3
PD10.Signal=FSMC_D15
PD11.Signal=FSMC_A16
PD12.GPIO_Label=TIM4_CH1_ENC2
PD12.Signal=S_TIM4_CH1
PD13.GPIO_Label=TIM4_CH2_ENC2
PD13.Signal=S_TIM4_CH2
PD14.Signal=FSMC_D0
PD15.Signal=FSMC_D1
PD2.Signal=SDIO_CMD
PD4.Signal=FSMC_NOE
PD5.Signal=FSMC_NWE
PD7.Signal=FSMC_NE1
PD8.Signal=FSMC_D13
PD9.Signal=FSMC_D14
PE10.Signal=FSMC_D7
PE11.Signal=FSMC_D8
PE12.Signal=FSMC_D9
PE13.Signal=FSMC_D10
PE14.Signal=FSMC_D11
PE15.Signal=FSMC_D12
PE3.GPIO_Label=BTN1
PE3.Signal=GPIO_Input
PE4.GPIO_Label=BTN2
PE4.Signal=GPIO_Input
PE5.GPIO_Label=SW1
PE5.Signal=GPIO_Input
PE6.GPIO_Label=SW2
PE6.Signal=GPIO_Input
PE7.Signal=FSMC_D4
PE8.Signal=FSMC_D5
PE9.Signal=FSMC_D6
PH0-OSC_IN.Signal=RCC_OSC_IN
PH1-OSC_OUT.Signal=RCC_OSC_OUT
